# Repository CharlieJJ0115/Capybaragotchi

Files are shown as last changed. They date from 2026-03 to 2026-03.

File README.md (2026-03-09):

# CapybaraGotchi 🦫🎮

A digital pet game implemented on FPGA, inspired by Tamagotchi, featuring a capybara-themed interactive experience.

This project was developed for **NTHU CS2104 Hardware Design Lab**.

---
## Demo Video 🎥

CapybaraGotchi Demo (https://www.youtube.com/watch?v=ZWOgOFY7l-o)
# Project Overview

CapybaraGotchi is a handheld electronic pet game built on FPGA.  
Players interact with a capybara using a joystick and ultrasonic sensor while viewing animations on an LCD screen.

The system is implemented using **Verilog** and designed as a collection of **finite state machines (FSMs)** controlling the pet’s behavior, scenes, and user interface.

---

# Features

## Pet States
The capybara can perform several behaviors:

- Idle
- Sleep
- Walk
- Feed
- Touch interaction

Each state has its own animation displayed on the LCD.

---

## Gameplay
Players can interact with the capybara through different activities:

- Feed the capybara
- Clean after it
- Interact using joystick
- Play a mini-game
- Touching its' head

---

## Additional Features

Additional features implemented in the project:

- Weather system
- Hot spring event
- Different foods depending on weather
- Hunger status
- Life status

---

# Hardware Components

The system integrates several hardware modules:

- FPGA board
- LCD display
- Joystick (player control)
- Ultrasonic sensor (touch detection)
- 3D printed handheld case

---

# System Architecture

The project is structured around three major **finite state machines (FSMs)**.

## 1. Scene FSM

Controls the main scenes of the game:

- DEFAULT
- HOTSPRING
- POOPING
- PLAY (mini game)
- GAME END

---

## 2. Capybara State FSM

Controls the capybara’s behavior:

- IDLE
- SLEEP
- WALK
- FEED
- TOUCH

Each state corresponds to a different animation displayed on the screen.

---

## 3. Lower Screen FSM

Controls the UI displayed at the bottom of the screen:

- INIT (status display)
- MENU
- SELECT_FOOD
- CLEAN

---

# Animation System

Animations are implemented using:

- Frame controller
- BRAM stored sprite frames
- Address generators for sprite positioning

The capybara sprite can move across the screen, turn direction, and perform animations by switching between frames stored in BRAM.

---

# Mini Game

A mini-game is included in the PLAY scene.

Gameplay mechanics:

- The player controls a cup using the joystick
- A ball bounces around the screen
- The player must catch the ball with the capybara's head
- Missing the ball results in game over

Collision detection and movement logic are implemented in Verilog.

---

# Mechanical Design

The handheld device uses a **three-layer 3D printed structure**:

1. Top layer – LCD and joystick mount  
2. Middle layer – structural support and wiring path  
3. Bottom layer – FPGA board and ultrasonic sensor  

The case design allows easy assembly and maintenance.

---

# Technologies Used

- Verilog HDL
- FPGA development (Vivado)
- LCD SPI interface
- Joystick input module
- Ultrasonic sensor module

---

# Team

Team 18 – HardcoreDesign

Members:
- 江善有
- 林亮宏

## Contribution

The project was developed collaboratively with an approximate **50 / 50 contribution split**.

- **江善有**  
  Responsible for the main Verilog implementation, including the top module, FSM design, and overall system logic.

- **林亮宏**  
  Responsible for sprite/animation image generation (COE files), joystick module implementation, FSM design , and assisting with debugging and testing.

Both members collaborated on system design discussions and hardware integration.

# Acknowledgements

Some modules were adapted from existing resources:

- SPI LCD module (online resources)
- Digilent joystick reference
- Ultrasonic sensor module from lab materials

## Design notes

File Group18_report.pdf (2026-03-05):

CS2104 01 | Hardware Design Lab | Lab Report

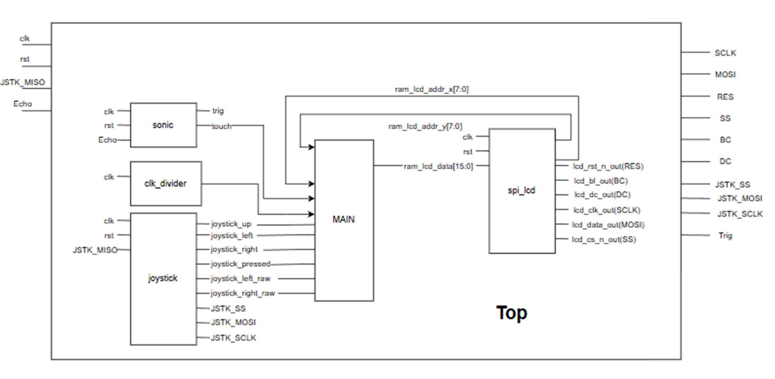
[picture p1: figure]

2025 | Chih-Tsun Huang | 1 / 14
Team No: 18 | Team Name: HardcoreDesign

## Project Title: CapybaraGotchi

Name: 江善有 | ID: 112033254
Name: 林亮宏 | ID: 113062339

## A. Project description

我們這組的主題是電子雞，並將其做成掌上遊戲機的形式。

## 當初會想要做這個主題是因為看到別人手上拿著的電子雞，當下就覺得其實電子雞就是㇐個 state machine，很適合使用 verilog 實作出來，而林亮宏又很喜歡使用卡皮巴拉主題的 line 貼圖，所以我 們決定客製化的做我們自己喜歡的電子雞。

## B. System architect and block diagram

### 組成的零件為 joystick, LCD 螢幕, ultrasonic sensor 及外殼。Joystick 為玩家主要的操控方式，而 ultrasonic sensor 則是用來實現 touch 功能。

下圖為我們的 top module，joystick module 過修改會傳出 one pulse 過的 up, down, left, right,
pressed 等訊號，用來操作互動選單，其中的”raw”訊號表示沒有經過 one pulse，用來實現卡皮 巴拉頂球小遊戲內的咖啡杯連續移動功能。LCD module 則是我們用來輸出的模組，可以看到與 vga 類似，都有用來表示座標的訊號和要傳入的顏色訊號，只是這個模組需要 16 bit 的

### pixel_data。

### 我們的程式部分可以分成三個 FSM，分別是 scene, capy_state, low_screen

### 1. scene: 場景的切換，一般的互動都會在 DEFAULT scene 內進行，泡湯、排泄、玩遊戲、遊戲

結束等特別的情況才會進入其他 scene。

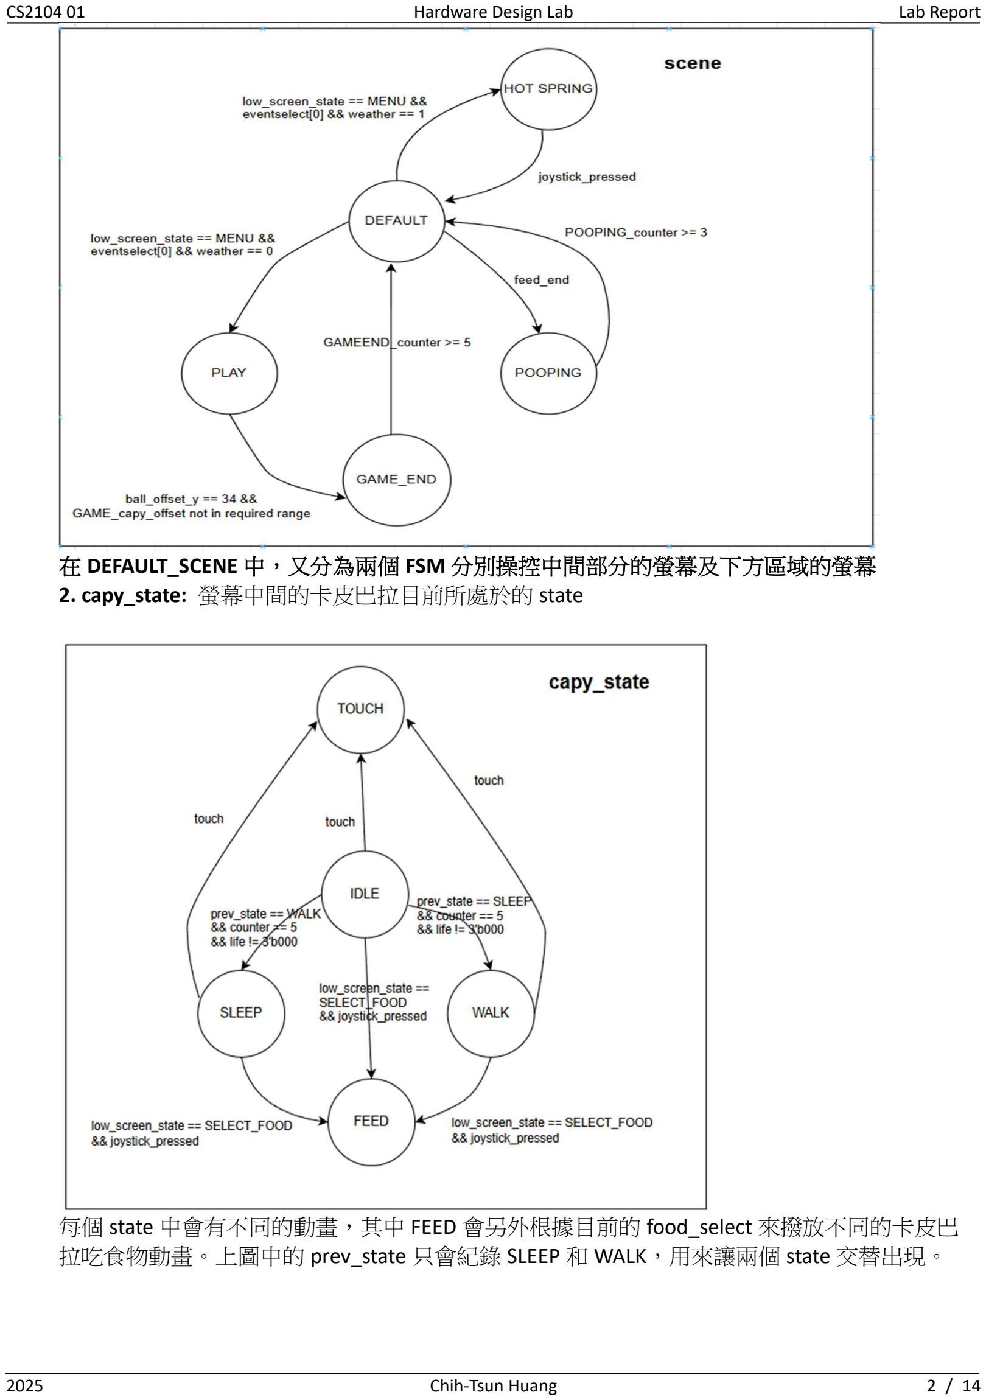
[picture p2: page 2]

2025 | Chih-Tsun Huang | 2 / 14

在 DEFAULT_SCENE 中，又分為兩個 FSM 分別操控中間部分的螢幕及下方區域的螢幕

### 2. capy_state: 螢幕中間的卡皮巴拉目前所處於的 state

每個 state 中會有不同的動畫，其中 FEED 會另外根據目前的 food_select 來撥放不同的卡皮巴 拉吃食物動畫。上圖中的 prev_state 只會紀錄 SLEEP 和 WALK，用來讓兩個 state 交替出現。

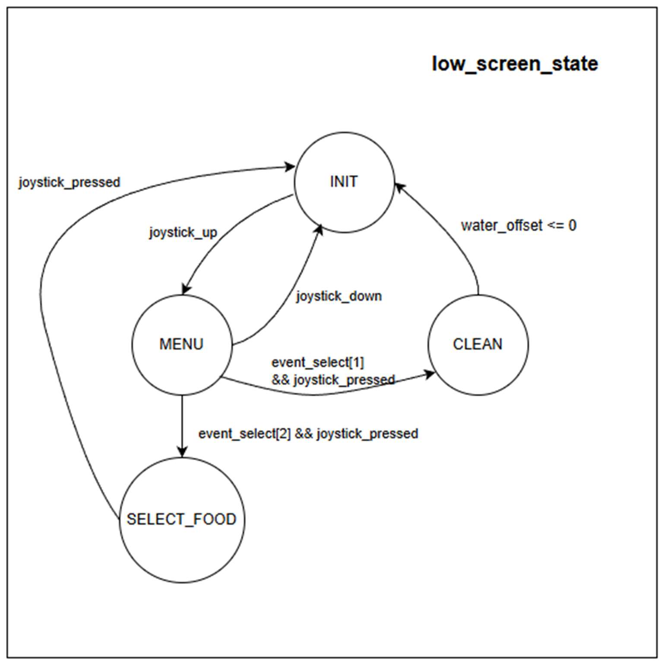
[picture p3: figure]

2025 | Chih-Tsun Huang | 3 / 14

### 3. low_screen_state: 螢幕下方顯示什麼的 state

### INIT: 根據 poop_count 顯示排泄物

MENU: 顯示互動選單

### SELECT_FOOD: 顯示餵食食物選單

CLEAN: 根據 water_offset 決定要跟 INIT 顯示一樣內容，還是水紋(用來呈現出沖水動畫)。

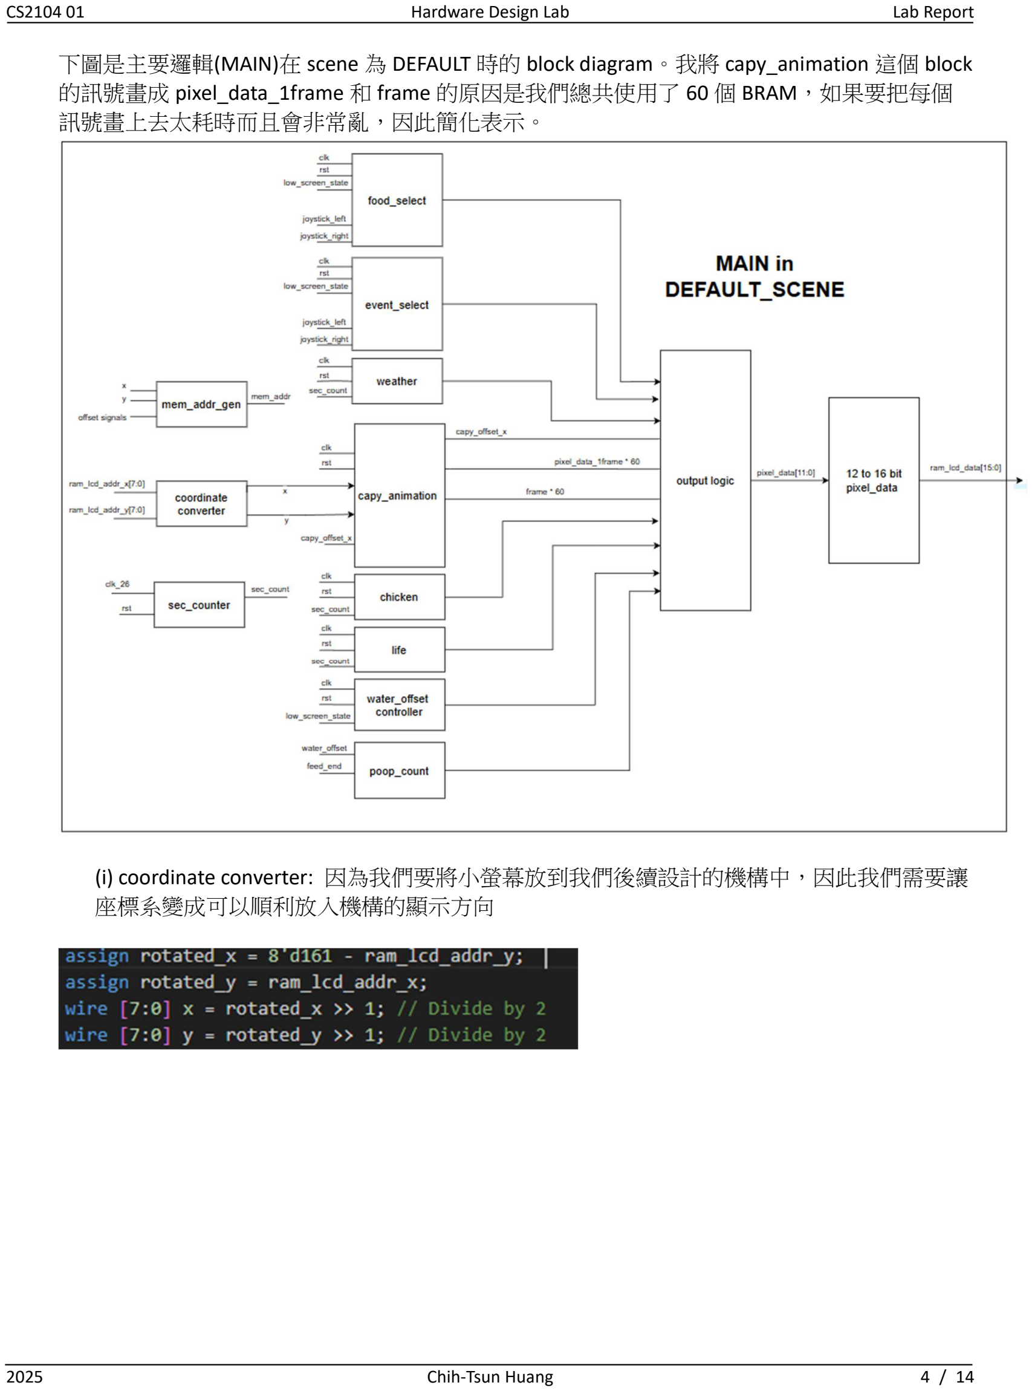
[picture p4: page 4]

2025 | Chih-Tsun Huang | 4 / 14

### 下圖是主要邏輯(MAIN)在 scene 為 DEFAULT 時的 block diagram。我將 capy_animation 這個 block 的訊號畫成 pixel_data_1frame 和 frame 的原因是我們總共使用了 60 個 BRAM，如果要把每個

訊號畫上去太耗時而且會非常亂，因此簡化表示。

(i) coordinate converter: 因為我們要將小螢幕放到我們後續設計的機構中，因此我們需要讓 座標系變成可以順利放入機構的顯示方向

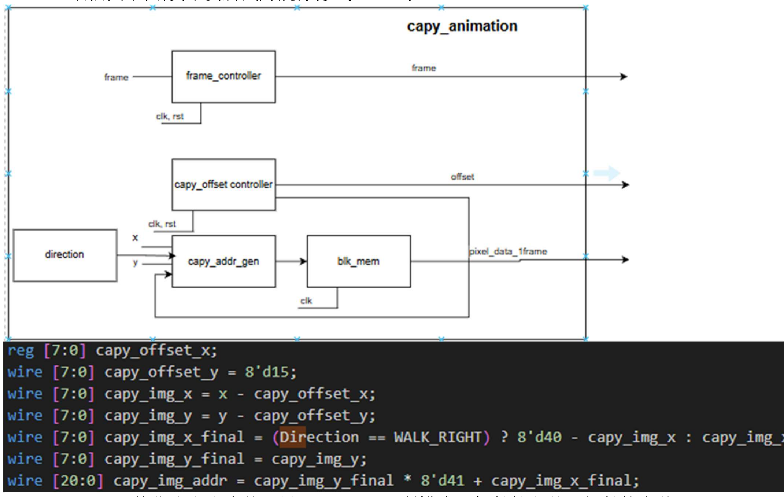
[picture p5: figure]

2025 | Chih-Tsun Huang | 5 / 14

### (ii) capy animation: 我們的卡皮巴拉會在螢幕上走動(capy_offset controller)，並且會自動回

頭(direction)，動畫則是由一幀一幀的圖片所組成，因此需要 frame controller 和每一個幀的

### pixel_data，capy_addr_gen 則是每個圖片會根據位置(capy_offset)的不同數值來計算，而 Direction 則用來判斷要不要將圖片鏡像(參考 lab5-1)

### (iii) chicken, life: 飽腹度和生命值，是 shift register 所構成，扣數值左移，加數值右移，並 將 MSB 變成 1。當 sec_count 中的 sec_count_DEFAULTSCENE 每到一定數值就會觸發扣數值

效果，feed_end 時會增加數值(詳細機制可參考 demo 影片)。

### (iv) food_select, event_select: 是 one hot 的 shift register，根據目前的 low_screen_state 來決

定會不會被改值

### (v) weather: 在 DEFAULT scene 中每十秒切換一次 (vi) water_offset_controller: 初始值為 81，當 low_screen_state == CLEAN 時會減少，用來計 算 water 的 memory address 及判斷是否要清空 poop_count 和 state transition (vii) poop_count: feed_end 時會加 1，當 CLEAN state 結束時(water_offset == 0)，會清 0。

### (viii) output_logic, 12 to 16 bit converter: 用上述訊號產出正確的 pixel_data。基本上就是分成 一堆 case，assign 不同的 blk_mem 產出的 pixel_data_1frame 給 pixel_data，再轉換成 16bit。

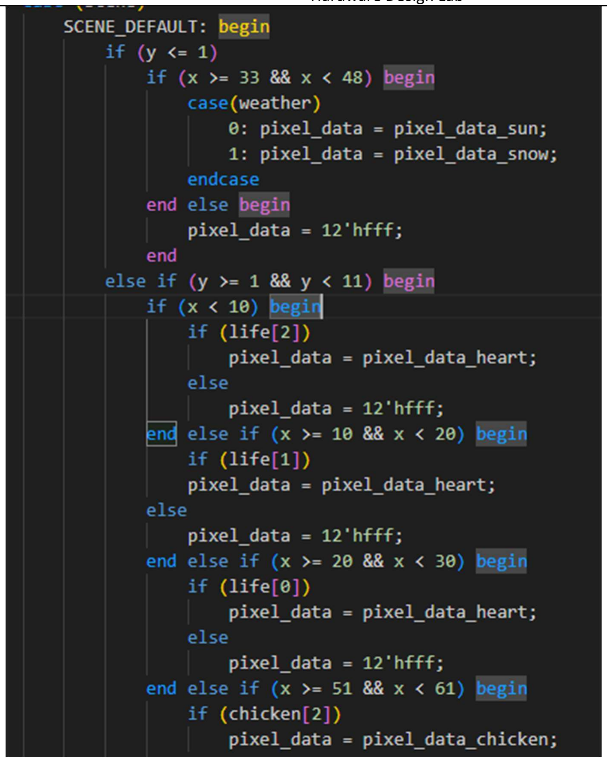
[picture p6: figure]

2025 | Chih-Tsun Huang | 6 / 14

### 在 GAMEEND、POOPING、HOTSPRING 等 Scene 中所使用的操控方式與 capy animation control 一樣都是使用 frame controller 的方式來做出動畫，因此不再贅述。

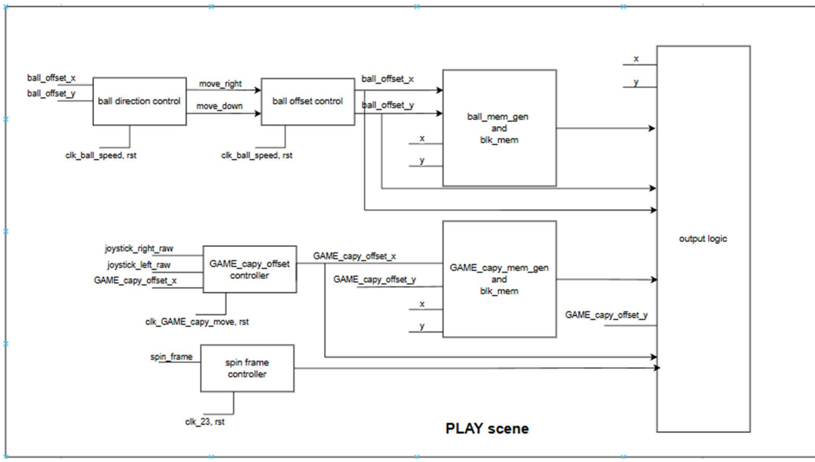
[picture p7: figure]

2025 | Chih-Tsun Huang | 7 / 14

## PLAY scene

### 在 PLAY scene 中，卡皮巴拉旋轉杯的方式與 DEFAULT scene 類似，只是透過 joystick 來操作

offset 而不是自動變化，可以看到這邊使用的 joystick 訊號是沒有 one pulse 過的。而球的 反彈則是觸摸的邊界就將對應 direction 相反，如果是接觸到卡皮巴拉頭頂的邊界，就觸發 判斷卡皮巴拉 offset 的位置是否有頂到球，如果是則反彈，若不是則遊戲結束。

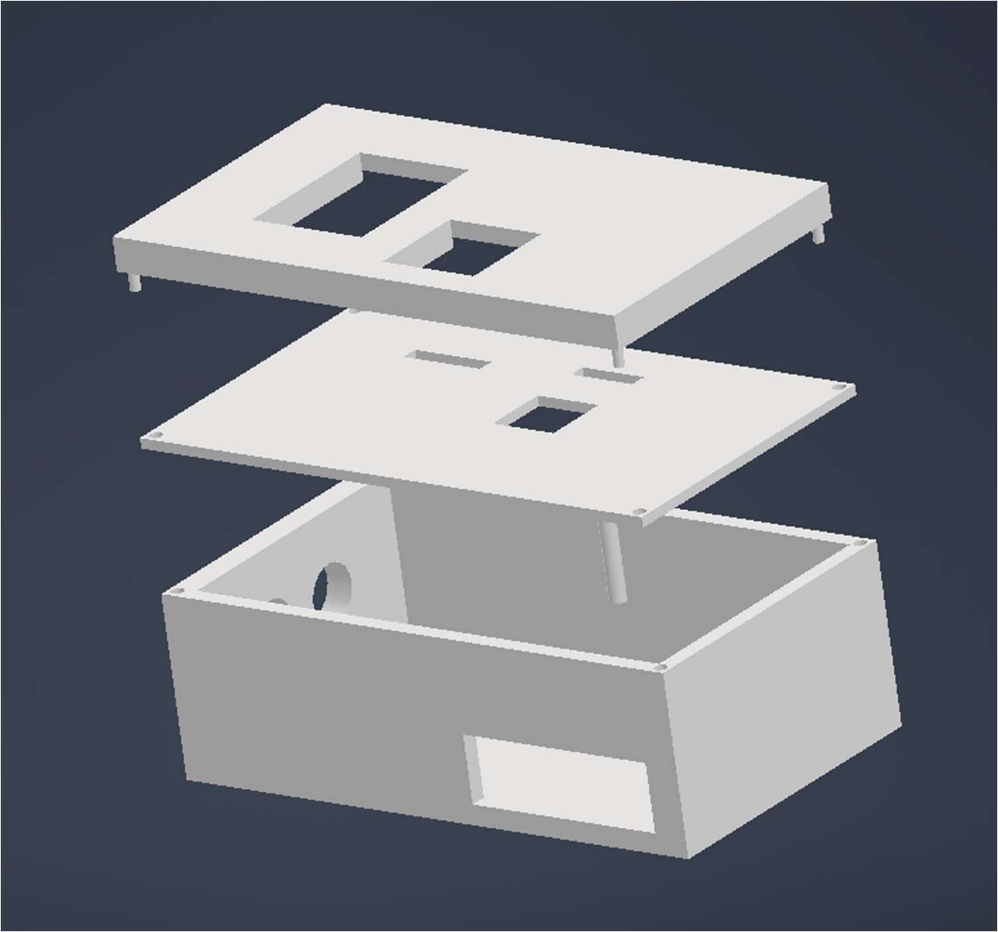
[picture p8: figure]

2025 | Chih-Tsun Huang | 8 / 14

機構設計

分為三層的組合結構(上圖)，四個角的小柱子用於固定 xy 平面不會滑動，因時間有限且需 要方便拆卸的考量，我們沒有固定 z 軸的設計，最上層用於固定螢幕和搖桿，中間層用於 支撐螢幕和搖桿並讓杜邦線從板子連上來，並加了一個支柱讓板子在內部不會大幅晃動，

### 下層用於容納 FPGA 板和 ultrasonic sensor，挖了洞來放置 ultrasonic sensor 和 program device。

特別感謝 DIT 機器人實驗室借我們列印機使用。
因為列印一次需要 4 個半小時，且我們列印一次要占用兩台機器，所以我們以可以使用為 主，預留了一些計算錯誤的容錯率，讓每個固定點都有一個方向的自由度。所幸誤差不大 最後列印出來只有四個角的固定孔需要手動鑽大。

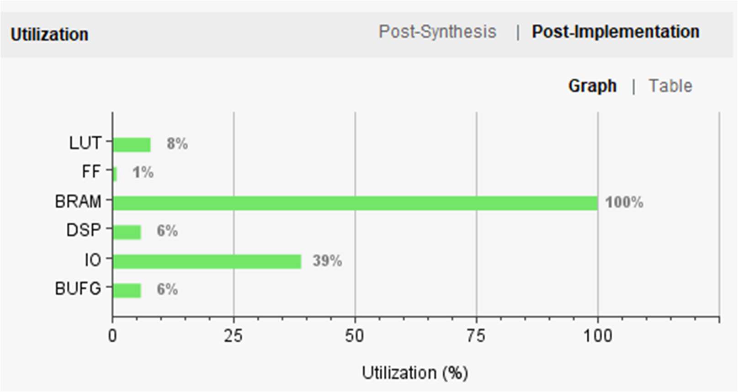
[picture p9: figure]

2025 | Chih-Tsun Huang | 9 / 14

## C. Implementation progress/ Testing completeness

type | Feature | status | 備註
Under planning | IDLE | Complete
Under planning | SLEEP | Complete
Under planning | WALK | Complete
Under planning | SICK | Complete
Under planning | FEED | Complete
Under planning | CLEAN | Complete
Under planning | PLAY(GAME) | Complete | 無加速度效果, 積分
Additional | weather | Complete
Additional | Event change(HOTSPRING) | Complete | Based on weather
Additional | Food change(Popsticle) | Complete | Based on weather
Additional | Life and hungry point | Complete
我們其實是有時間嘗試完成小遊戲的加速度效果和積分的，但我們開始做 weather 後希望可以 把整體功能完善，才會比較有掌上型遊戲機的感覺，做完 Additional 的功能後發現 BRAM 被我 們用完了，所以就決定先到此為止以外觀的美術為主。

## D. Technical challenges and Solutions

因為我們在學期間測試外接設備時就把設計草稿做完了，在實作的過程中沒有遇到太大的困 難，基本上就是一些可以觀察出規律的問題，但比較神奇的是我們將 spin_frame 的 clk 用成 clk_23 時，會無法進入遊戲的 state，但改成 clk_25, clk_24 就可以，後續我們又改回 clk_23 又可以了，相當 神奇。
初期我們在測試網路上找到的 lcd 螢幕模組時，撇除掉我們看教學文接錯線的部分不看，其他 部分都蠻順利的，但我們後續發現該模組只會在 program 完後在初始化的狀態 scan 一次圖片，我們 當時是有嚇到因為在這之前都只是測試座標以及顏色的部分，沒想到會發生這種事，好在我們發現 只要改掉 MAIN 裡面的 next_state logic，讓 SCAN 可以被重複進入就修好了。下圖為前(左)後(右)對比 圖。

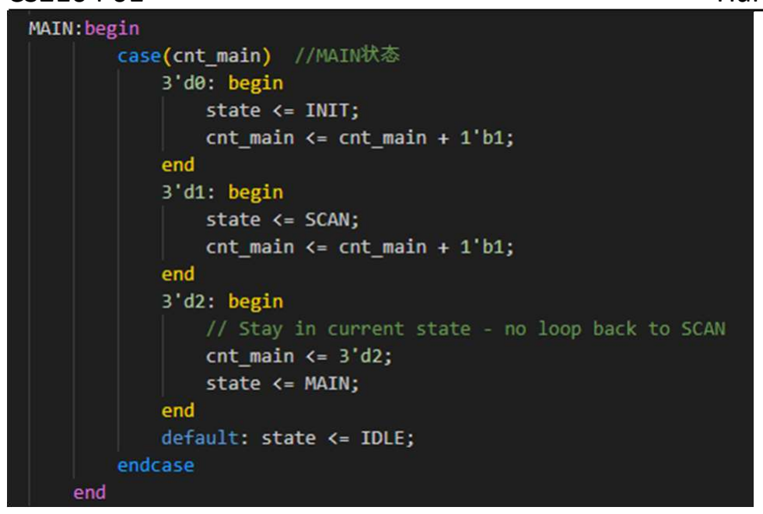
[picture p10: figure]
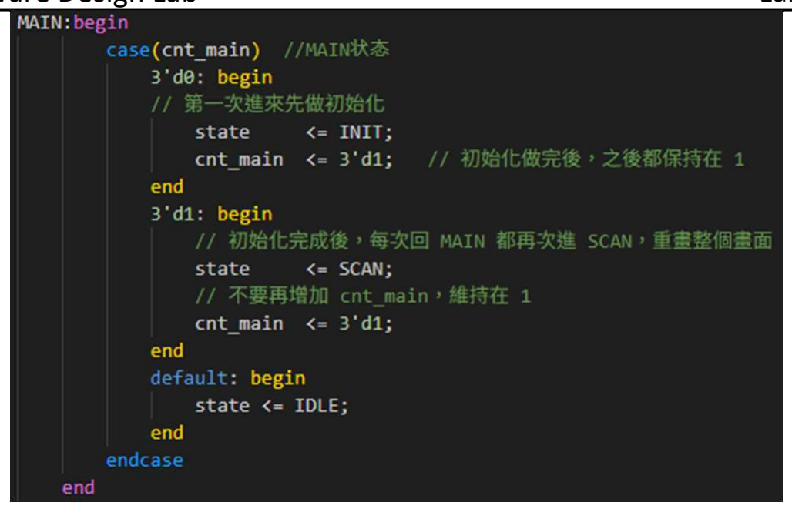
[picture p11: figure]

2025 | Chih-Tsun Huang | 10 / 14

## E. Reflections and Discussions

這次的 project 是我們都認為最好玩、最有成就感的 project，也真的體會到老師說的:「先設 計，後續比較容易 debug」的感覺，這次因為我們一開始就把大致的系統架構都設計好了才開 始做，所以在實作時就是多加一些細節的訊號和解決一些枝微末節的小問題，並沒有遇到需要 大改程式的時候，並且我們保持著新增功能只會增加新訊號或用本來就有的訊號，而不會去改 已經有東西在使用的訊號的實作方式，讓整個 project 很好擴充，所以當時林亮宏說泡溫泉的 貼圖很可愛時，但不知道這個功能的按鍵要放哪裡，才能想到天氣系統，並且要改的東西也不 多，也不會互相影響，一直做到 BRAM 用完才停止。

### 不過這次專案似乎有很多同學遇到 Access violation 的問題(沒有報錯訊息的 synthesize fail)，我

自己是在 advanced lab 就遇過了，當時是王定庭助教和黃威儒助教幫我看問題出在哪的，後續 使用助教的 2024 版 vivado 一下就合成成功了，再次感謝助教們的幫助。 因此有同學遇到這個問題時我就跟他們說去試試 2024 版 vivado，也都有成功合成，我自己的 觀察是似乎他們都有接鍵盤與使用二維陣列(我自己在 advanced lab 當時也是)，但我並沒有仔 細的驗證，只是覺得可以提供一下參考說不定以後就不用有人因此坐牢了(是真的很痛苦，現 在看到有錯誤訊息反而覺得人生真美好)。

## F. Detailed task division

## 我們在做這個 project 的時候都是㇐起待在資電館三樓沙發，就如 demo 時所說，我們先將大概要做 甚麼討論好，接著江善有負責寫 code，林亮宏產生圖片的 coe 檔，江善有寫完後如果出現問題，則 由林亮宏檢查，經討論後大部分問題幾乎都在半小時內解決。因為我們基本上待在㇐起做完所有 事，所以 contribution 50 / 50。外殼部分則是我們㇐起想需求與嘗試。

### Top module(主要架構)程式碼: 江善有 Top module review: 林亮宏 COE files: 林亮宏 Joystick module : 林亮宏 外殼: both 江善有: 50% 林亮宏: 50%

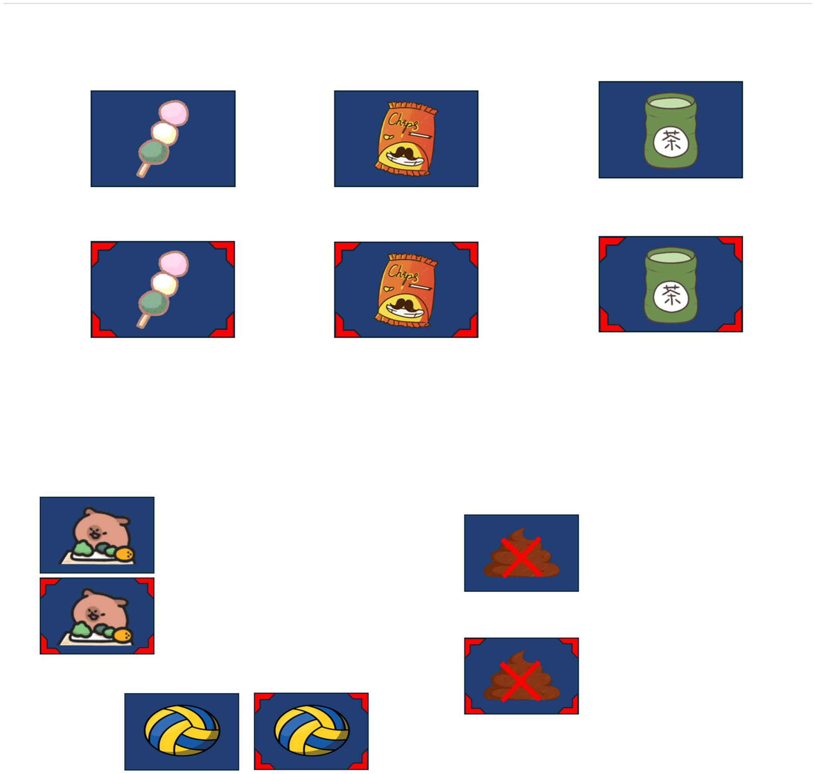
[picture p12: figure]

2025 | Chih-Tsun Huang | 11 / 14

## G. Degree of independent work

1. spi_lcd module : found on internet, but can only scan one picture.

## https://chipdebug.com/forum-post/54008.html www.stepfpga.com 2. joystick: Original from demo project https://digilent.com/reference/pmod/pmodjstk2/start 3. sonic.v: from lab 6 advanced

附錄:

## 1. menu UI:

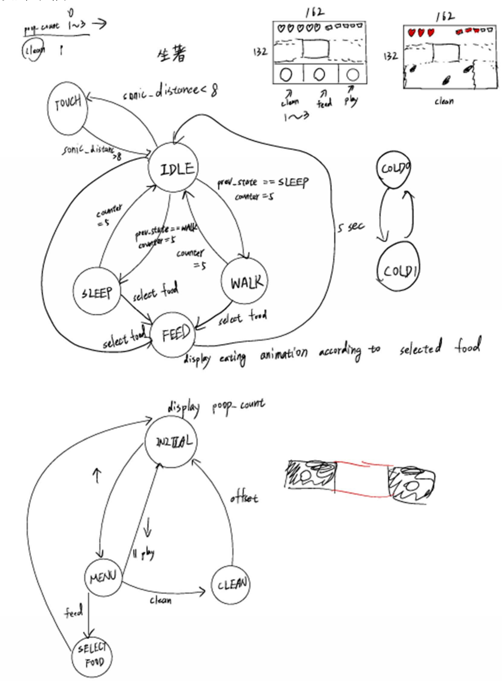
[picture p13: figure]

2025 | Chih-Tsun Huang | 12 / 14

### 2. 設計手稿:

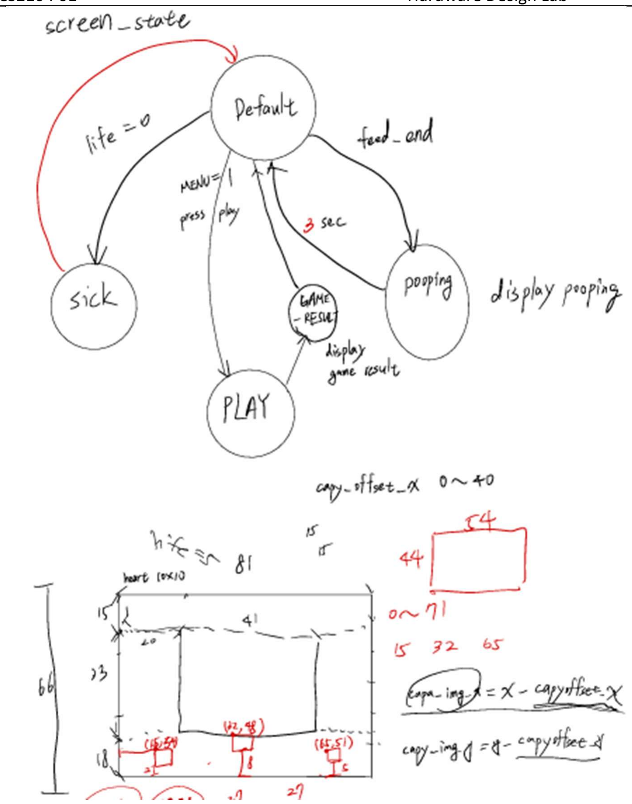
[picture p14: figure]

2025 | Chih-Tsun Huang | 13 / 14

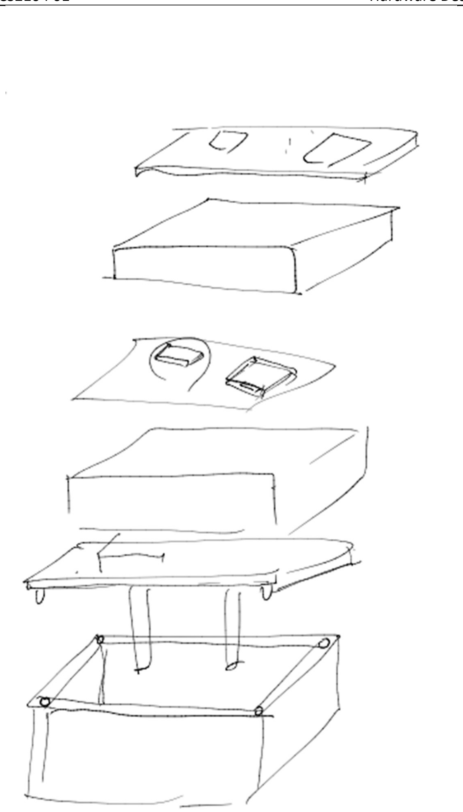
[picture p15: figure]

2025 | Chih-Tsun Huang | 14 / 14

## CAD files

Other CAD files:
零件1.ipt
零件2.ipt
零件3.ipt

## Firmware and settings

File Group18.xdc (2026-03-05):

## This file is a general .xdc for the Basys3 rev B board
## To use it in a project:
## - uncomment the lines corresponding to used pins
##   (if you are using the editor in Vivado, you can select lines and hit "Ctrl + /" to comment/uncomment.)
## - rename the used ports (in each line, after get_ports) according to the top level signal names in the project

# Clock signal
set_property PACKAGE_PIN W5 [get_ports clk]
set_property IOSTANDARD LVCMOS33 [get_ports clk]
create_clock -period 10.000 -name sys_clk_pin -waveform {0.000 5.000} -add [get_ports clk]

# Switches
# set_property PACKAGE_PIN V17 [get_ports {enable}]
# set_property IOSTANDARD LVCMOS33 [get_ports {enable}]
#set_property PACKAGE_PIN V16 [get_ports {motor_l_enable}]
#set_property IOSTANDARD LVCMOS33 [get_ports {motor_l_enable}]
#set_property PACKAGE_PIN W16 [get_ports {motor_l_dir}]
#set_property IOSTANDARD LVCMOS33 [get_ports {motor_l_dir}]
#set_property PACKAGE_PIN W17 [get_ports {motor_r_enable}]
#set_property IOSTANDARD LVCMOS33 [get_ports {motor_r_enable}]
#set_property PACKAGE_PIN W15 [get_ports {motor_r_dir}]
#set_property IOSTANDARD LVCMOS33 [get_ports {motor_r_dir}]
# set_property PACKAGE_PIN V15 [get_ports {relay_enable}]
#    set_property IOSTANDARD LVCMOS33 [get_ports {relay_enable}]
# set_property PACKAGE_PIN W14 [get_ports {cur_state[0]}]
#    set_property IOSTANDARD LVCMOS33 [get_ports {cur_state[0]}]
# set_property PACKAGE_PIN W13 [get_ports {cur_state[1]}]
#    set_property IOSTANDARD LVCMOS33 [get_ports {cur_state[1]}]
# set_property PACKAGE_PIN V2 [get_ports {sw[8]}]
#    set_property IOSTANDARD LVCMOS33 [get_ports {sw[8]}]
# set_property PACKAGE_PIN T3 [get_ports {sw[9]}]
#    set_property IOSTANDARD LVCMOS33 [get_ports {sw[9]}]
# set_property PACKAGE_PIN T2 [get_ports {sw[10]}]
#    set_property IOSTANDARD LVCMOS33 [get_ports {sw[10]}]
# set_property PACKAGE_PIN R3 [get_ports {sw[11]}]
#    set_property IOSTANDARD LVCMOS33 [get_ports {sw[11]}]
# set_property PACKAGE_PIN W2 [get_ports {sw[12]}]
#    set_property IOSTANDARD LVCMOS33 [get_ports {sw[12]}]
# set_property PACKAGE_PIN U1 [get_ports {sw[13]}]
#    set_property IOSTANDARD LVCMOS33 [get_ports {sw[13]}]
# set_property PACKAGE_PIN T1 [get_ports {sw[14]}]
#    set_property IOSTANDARD LVCMOS33 [get_ports {sw[14]}]
# set_property PACKAGE_PIN R2 [get_ports {sw[15]}]
#    set_property IOSTANDARD LVCMOS33 [get_ports {sw[15]}]


# # LEDs
 set_property PACKAGE_PIN U16 [get_ports {LED[0]}]
     set_property IOSTANDARD LVCMOS33 [get_ports {LED[0]}]
 set_property PACKAGE_PIN E19 [get_ports {LED[1]}]
     set_property IOSTANDARD LVCMOS33 [get_ports {LED[1]}]
 set_property PACKAGE_PIN U19 [get_ports {LED[2]}]
     set_property IOSTANDARD LVCMOS33 [get_ports {LED[2]}]
set_property PACKAGE_PIN V19 [get_ports {LED[3]}]
    set_property IOSTANDARD LVCMOS33 [get_ports {LED[3]}]
set_property PACKAGE_PIN W18 [get_ports {LED[4]}]
    set_property IOSTANDARD LVCMOS33 [get_ports {LED[4]}]
set_property PACKAGE_PIN U15 [get_ports {LED[5]}]
    set_property IOSTANDARD LVCMOS33 [get_ports {LED[5]}]
set_property PACKAGE_PIN U14 [get_ports {LED[6]}]
    set_property IOSTANDARD LVCMOS33 [get_ports {LED[6]}]
set_property PACKAGE_PIN V14 [get_ports {LED[7]}]
    set_property IOSTANDARD LVCMOS33 [get_ports {LED[7]}]
set_property PACKAGE_PIN V13 [get_ports {LED[8]}]
    set_property IOSTANDARD LVCMOS33 [get_ports {LED[8]}]
set_property PACKAGE_PIN V3 [get_ports {LED[9]}]
    set_property IOSTANDARD LVCMOS33 [get_ports {LED[9]}]
set_property PACKAGE_PIN W3 [get_ports {LED[10]}]
    set_property IOSTANDARD LVCMOS33 [get_ports {LED[10]}]
set_property PACKAGE_PIN U3 [get_ports {LED[11]}]
    set_property IOSTANDARD LVCMOS33 [get_ports {LED[11]}]
set_property PACKAGE_PIN P3 [get_ports {LED[12]}]
    set_property IOSTANDARD LVCMOS33 [get_ports {LED[12]}]
set_property PACKAGE_PIN N3 [get_ports {LED[13]}]
    set_property IOSTANDARD LVCMOS33 [get_ports {LED[13]}]
set_property PACKAGE_PIN P1 [get_ports {LED[14]}]
    set_property IOSTANDARD LVCMOS33 [get_ports {LED[14]}]
set_property PACKAGE_PIN L1 [get_ports {LED[15]}]
    set_property IOSTANDARD LVCMOS33 [get_ports {LED[15]}]


# 7 segment display
 set_property PACKAGE_PIN W7 [get_ports {DISPLAY[0]}]
    set_property IOSTANDARD LVCMOS33 [get_ports {DISPLAY[0]}]
 set_property PACKAGE_PIN W6 [get_ports {DISPLAY[1]}]
    set_property IOSTANDARD LVCMOS33 [get_ports {DISPLAY[1]}]
 set_property PACKAGE_PIN U8 [get_ports {DISPLAY[2]}]
    set_property IOSTANDARD LVCMOS33 [get_ports {DISPLAY[2]}]
 set_property PACKAGE_PIN V8 [get_ports {DISPLAY[3]}]
    set_property IOSTANDARD LVCMOS33 [get_ports {DISPLAY[3]}]
 set_property PACKAGE_PIN U5 [get_ports {DISPLAY[4]}]
    set_property IOSTANDARD LVCMOS33 [get_ports {DISPLAY[4]}]
 set_property PACKAGE_PIN V5 [get_ports {DISPLAY[5]}]
    set_property IOSTANDARD LVCMOS33 [get_ports {DISPLAY[5]}]
 set_property PACKAGE_PIN U7 [get_ports {DISPLAY[6]}]
    set_property IOSTANDARD LVCMOS33 [get_ports {DISPLAY[6]}]
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

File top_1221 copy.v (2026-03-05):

`timescale 1ns / 1ps
//////////////////////////////////////////////////////////////////////////////////
// Module Name: top
// Description: Top level module for SPI LCD display controller
//////////////////////////////////////////////////////////////////////////////////
module top(
    input wire clk,           // System clock (100MHz from Basys3)
    input wire rst,         // Reset signal (active high)
    output wire SCLK,         // SPI clock
    output wire MOSI,         // SPI data (Master Out Slave In)
    output wire RES,          // LCD reset
    output wire SS,           // SPI chip select
    output wire BC,           // LCD backlight/DC control
    output wire DC,           // SPI data (Master In Slave Out) - unused but in XDC
    // Joystick SPI interface
    input wire JSTK_MISO,     // Joystick MISO
    output wire JSTK_SS,      // Joystick S
    

    output wire JSTK_MOSI,    // Joystick MOSI
    output wire JSTK_SCLK,     // Joystick SCLK
    // Sonic sensor interface
    input wire Echo,          // Sonic sensor echo
    output wire Trig,         // Sonic sensor trigger
    output reg [15:0] LED,
    output wire [6:0] DISPLAY,
    output wire [3:0] DIGIT
);
    
    // Internal signals for LCD pixel data
    wire [15:0] ram_lcd_data;
    wire [7:0] ram_lcd_addr_x;
    wire [7:0] ram_lcd_addr_y;
    
    // Clock divider: 100MHz -> 10MHz
    reg [2:0] clk_div_counter = 0;
    reg clk_divided = 0;

    reg [15:0] distance_display;
    wire [19:0] distance;
    
    always @(posedge clk or posedge rst) begin
        if (rst) begin
            clk_div_counter <= 0;
            clk_divided <= 0;
        end else begin
            if (clk_div_counter == 4) begin  // Divide by 10: 100MHz/10 = 10MHz
                clk_div_counter <= 0;
                clk_divided <= ~clk_divided;
            end else begin
                clk_div_counter <= clk_div_counter + 1;
            end
        end
    end
    
    // Instantiate the spi_lcd module
    spi_lcd #(
        .LCD_W(8'd132),
        .LCD_H(8'd162)
    ) lcd_inst (
        .clk(clk),
        .rst(rst),
        .ram_lcd_data(ram_lcd_data),
        .ram_lcd_addr_x(ram_lcd_addr_x),
        .ram_lcd_addr_y(ram_lcd_addr_y),
        .lcd_rst_n_out(RES),
        .lcd_bl_out(BC),
        .lcd_dc_out(DC),              // Not connected to external pin
        .lcd_clk_out(SCLK),
        .lcd_data_out(MOSI),
        .lcd_cs_n_out(SS)
    );
    // Joystick signals
    wire joystick_up, joystick_down, joystick_left, joystick_right, joystick_pressed, joystick_left_raw, joystick_right_raw;

    // Sonic sensor signal
    wire touch;

    PmodJSTK_Demo joystick(
        .CLK(clk),
        .RST(rst),
        .MISO(JSTK_MISO),
        .SS(JSTK_SS),
        .MOSI(JSTK_MOSI),
        .SCLK(JSTK_SCLK),
        .joystick_up(joystick_up),
        .joystick_down(joystick_down),
        .joystick_left(joystick_left),
        .joystick_right(joystick_right),
        .joystick_pressed(joystick_pressed),
        .joystick_left_raw(joystick_left_raw),
        .joystick_right_raw(joystick_right_raw)
    );

    // Instantiate sonic sensor module
    sonic_top sonic(
        .clk(clk),
        .rst(rst),
        .Echo(Echo),
        .Trig(Trig),
        .touch(touch),
        .dis(distance)
    );
	wire clk_25MHz, clk_26, clk_23;
    wire clk_WALK;
    wire clk_animation;
    wire clk_water;
    wire clk_GAME_capy_move;
    wire clk_ball_speed;
	clock_divider #(.n(2)) clk_div_inst (
		.clk(clk),
		.clk_div(clk_25MHz)
	);
	clock_divider #(.n(26)) clk_1sec (
		.clk(clk),
		.clk_div(clk_26)
	);
    clock_divider #(.n(24)) WALK_speed (
		.clk(clk),
		.clk_div(clk_WALK)
	);
	clock_divider #(.n(25)) animation_freq (
		.clk(clk),
		.clk_div(clk_animation)
	);
	clock_divider #(.n(22)) water_freq (
		.clk(clk),
		.clk_div(clk_water)
	);
    clock_divider #(.n(21)) GAME_capy_freq (
		.clk(clk),
		.clk_div(clk_GAME_capy_move)
	);
    clock_divider #(.n(23)) clk_23_freq (
		.clk(clk),
		.clk_div(clk_23)
	);
    clock_divider #(.n(22)) GAME_ball_speed (
		.clk(clk),
		.clk_div(clk_ball_speed)
	);
	// Calculate image address based on LCD coordinates (rotated 90 degrees)
	// Swap x and y, then flip: Display(x,y) -> Image(y, 131-x)
	// Add vertical offset to shift image up
	// parameter Y_OFFSET = 8'd25;  // Adjust this value to move image up/down
	wire [7:0] rotated_x;
	wire [7:0] rotated_y;
    reg Direction;
    parameter WALK_RIGHT = 1'b0;
    parameter WALK_LEFT = 1'b1;
	assign rotated_x = 8'd161 - ram_lcd_addr_y;  
	assign rotated_y = ram_lcd_addr_x;  
	wire [7:0] x = rotated_x >> 1; // Divide by 2
	wire [7:0] y = rotated_y >> 1; // Divide by 2
	reg [7:0] capy_offset_x;
    wire [7:0] capy_offset_y = 8'd15;
    wire [7:0] capy_img_x = x - capy_offset_x;
    wire [7:0] capy_img_y = y - capy_offset_y;
    wire [7:0] capy_img_x_final = (Direction == WALK_RIGHT) ? 8'd40 - capy_img_x : capy_img_x;
    wire [7:0] capy_img_y_final = capy_img_y;
    wire [20:0] capy_img_addr = capy_img_y_final * 8'd41 + capy_img_x_final;
    wire [9:0] heart_addr = (x % 10) + (y-1) * 10;
    wire [9:0] chicken_addr = ((x % 10) - 1 + (y-1) * 10);
    wire [9:0] menu_addr = (x % 27) + (y-48) * 27;
    reg [9:0] poop_addr_cal; 
    always @* begin
        if (x >= 15 && x < 25 && y >= 54 && y < 64) begin
            poop_addr_cal = (x - 15) + (y - 54) * 10;
        end else if (x >= 32 && x < 42 && y >= 48 && y < 58) begin
            poop_addr_cal = (x - 32) + (y - 48) * 10;
        end else if (x >= 65 && x < 75 && y >= 51 && y < 61) begin
            poop_addr_cal = (x - 65) + (y - 51) * 10;
        end else begin
            poop_addr_cal = 0;
        end
    end
    wire [9:0] poop_addr = poop_addr_cal;
    reg [15:0] pooping_scene_addr_cal;
    wire [15:0] pooping_scene_addr = pooping_scene_addr_cal;
    always @* begin
        if (x >= 13 && x < 67 && y >= 11 && y < 55) begin
            pooping_scene_addr_cal = (x-13) + (y-11) * 54;
        end else begin
            pooping_scene_addr_cal = 0; 
        end
    end
    reg [15:0] GAMEEND_scene_addr_cal;
    wire [15:0] GAMEEND_scene_addr = GAMEEND_scene_addr_cal;
    always @* begin
        if (x >= 13 && x < 67 && y >= 11 && y < 55) begin
            GAMEEND_scene_addr_cal = (x-13) + (y-11) * 54;
        end else begin
            GAMEEND_scene_addr_cal = 0; 
        end
    end
    wire [15:0] hotspring_scene_addr = GAMEEND_scene_addr;
    reg [7:0] water_offset;
    wire [15:0] water_addr = (x - water_offset) + (y-48) * 81;
    reg [7:0] GAME_capy_offset_x; 
    wire [7:0] GAME_capy_offset_y = 44;
    reg [7:0] GAME_ball_offset_x, GAME_ball_offset_y;
    wire [9:0] ball_addr = (x - GAME_ball_offset_x) + (y - GAME_ball_offset_y) * 10;
    wire [9:0] spin_addr = (x - GAME_capy_offset_x) + (y-44) * 27;
    wire [9:0] weather_addr = (x - 33) + y * 15;
    reg [2:0] capy_state, next_capy_state, capy_prev_state;
    reg [1:0] lowscreen_state, next_lowscreen_state;
    reg [2:0] scene, next_scene;
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
